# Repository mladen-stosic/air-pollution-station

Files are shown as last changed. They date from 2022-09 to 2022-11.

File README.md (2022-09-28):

# air-pollution-station
Arduino project

### Hardware used:
WeMos D1 Mini(ESP8266), PMSA003, BME280

### Project description:
Gather data from PMS and BME sensors and send them to opensensemap.org

### Implemetation:
After reset wake up PMS sensor, put it in passive mode. Try to connect to WiFi, if connection fails go to low power mode for 2 minutes.
When connected, wait 30 seconds for PMS Sensor to start sending valid values. Gather 4 different measurements from it and get their average value. This is done to increase accuracy. Gather data from BME Sensor. Send all gathered values to opensensemap.org server. Put PMS sensor to sleep. Enter deep sleep for 3 minutes, when MCU will be reset by internal clock pulling it's RST pin to GND.

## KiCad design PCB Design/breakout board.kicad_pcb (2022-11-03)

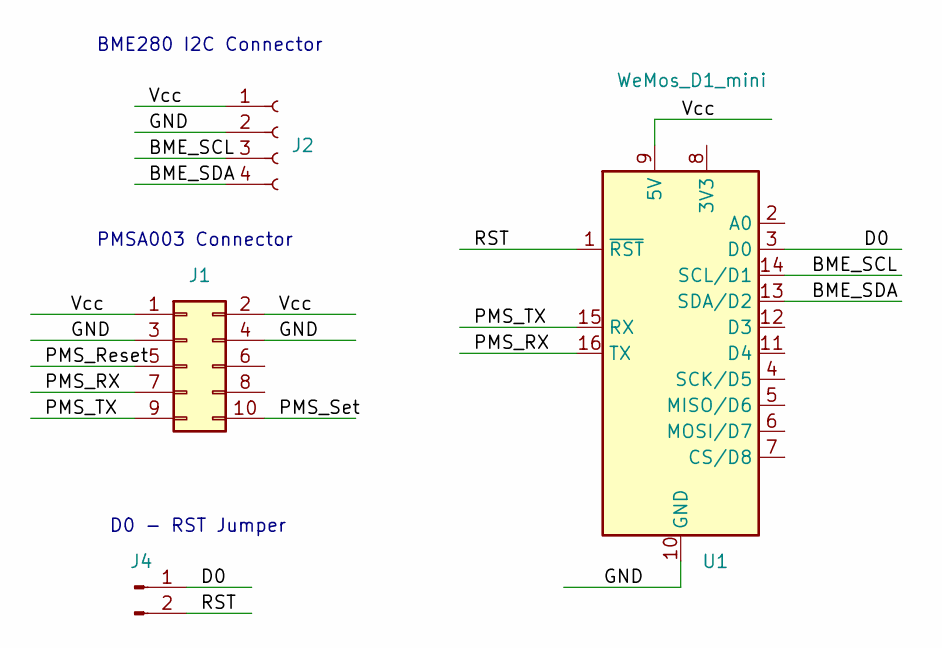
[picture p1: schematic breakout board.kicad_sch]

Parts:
J1: Conn_02x05_Odd_Even; PinHeader_2x05_P1.27mm_Vertical_SMD
J2: Conn_01x04_Female; PinHeader_1x04_P2.54mm_Vertical
J4: Conn_01x02_Male; PinHeader_1x02_P2.54mm_Vertical
U1: WeMos_D1_mini; WEMOS_D1_mini_light

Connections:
/BME_SCL: J2.3, U1.14 (SCL/D1)
/BME_SDA: J2.4, U1.13 (SDA/D2)
/D0: J4.1, U1.3 (D0)
/GND: J1.3, J1.4, J2.2, U1.10 (GND)
/PMS_RX: J1.7, U1.16 (TX)
/PMS_Reset: J1.5
/PMS_Set: J1.10
/PMS_TX: J1.9, U1.15 (RX)
/RST: J4.2, U1.1 (~RST)
/Vcc: J1.1, J1.2, J2.1, U1.9 (5V)

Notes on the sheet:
BME280 I2C Connector
PMSA003 Connector
D0 - RST Jumper

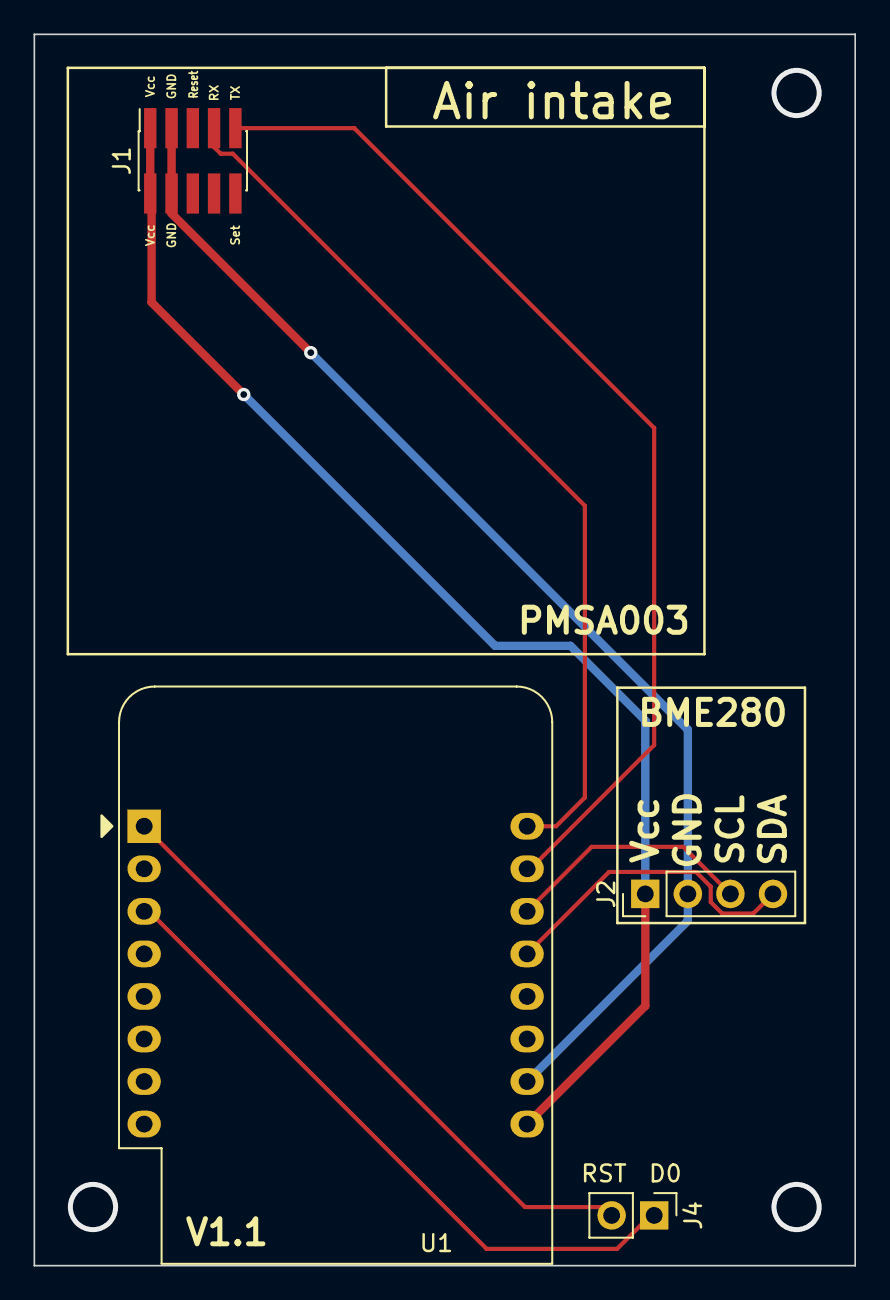
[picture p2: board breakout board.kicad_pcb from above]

Board: 2 copper layers, 49.0 x 73.5 mm, 4 parts (0 on the bottom side), 8 nets.

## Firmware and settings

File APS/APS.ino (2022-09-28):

/*

@author Mladen Stosic

@brief Air pollution station using WeMos D1 Mini,
PMSA003 and BME280
Data is sent to opensensemap.org approx every 3 minutes

Connections:

! D0 must be connected to RST !

BME280 -> WeMos D1 mini
SCL    -> SCL (PIN D1)
SDK    -> SDK (PIN D2)
GND    -> GND
VCC    -> Vcc

PMS -> WeMos D1 mini
TX  -> RX
RX  -> TX
GND -> GND
VCC -> Vcc

*/

#include <Wire.h>
#include <SPI.h>
#include <Adafruit_Sensor.h>
#include <Adafruit_BME280.h>
#include <PMS.h>
#include <ESP8266WiFi.h>
#include <stdint.h>


Adafruit_BME280 bme; // I2C
PMS pms(Serial);
PMS::DATA data;

// Network SSID
const char* ssid = "******";
const char* password = "******";

static String pressure;
static String temperature;
static String humidity;
static uint16_t pm1_0;
static uint16_t pm2_5;
static uint16_t pm10;
static uint16_t pm1_0rd[4];
static uint16_t pm2_5rd[4];
static uint16_t pm10rd[4];

static uint16_t wifiDelay = 0;

// Max Waiting time for WiFi Connection
#define WIFI_TIME_LIMIT 30*500
// Deep sleep time
#define DEEP_SLEEP_TIME 120e6
// 30s to get valid data from PMS
#define DATA_VALID_TIME 30000

// Personal sensor ID obtained from opensensemap.org
//senseBox ID
#define SENSEBOX_ID "**************"
//Sensor IDs
// Temperature - BME280
#define SENSOR1_ID "**************"
// Humidity - BME280
#define SENSOR2_ID "**************"
// Atmospheric pressure - BME280
#define SENSOR3_ID "**************"
// PM 1.0 - PMSA003
#define SENSOR4_ID "**************"
// PM 2.5 - PMSA003
#define SENSOR5_ID "**************"
// PM 10 - PMSA003
#define SENSOR6_ID "**************"

static char server[] = "ingress.opensensemap.org";
static byte mac[] = { 0xDE, 0xAD, 0xBE, 0xEF, 0xFE, 0xED };
IPAddress myIP(192, 168, 0, 42);
WiFiClient client;

// Send data to the server via WiFi
void sendData(String measurement, String sensorId){

  //Json fill
  String jsonValue = "{\"value\":";
  jsonValue += measurement;
  jsonValue += "}";

  if (client.connect(server, 80)){

    client.print("POST /boxes/"); client.print(SENSEBOX_ID); client.print("/"); client.print(sensorId); client.println(" HTTP/1.1");
    client.print("Host:");
    client.println(server);
    client.print("Authorization:");
    client.println("1cfd32ceb172e447b737c904c2eedf5d2cf9aba15ef65b8dd1015a46cafaa1e1");
    client.println("Content-Type: application/json");
    client.println("Connection: close");
    client.print("Content-Length: "); client.println(jsonValue.length());
    client.println();
    //Send data
    client.println(jsonValue);

    waitForServerResponse();

  } 
}

void waitForServerResponse () {
  if (!client.connected()) {
      client.stop();
      // Disable power to sensors
      pms.sleep();
      // Deep sleep for 1 minute
      ESP.deepSleep(DEEP_SLEEP_TIME / 2);
  }
}

// Read values from PMS Air quality sensor
void readPMS() {
  static uint8_t i;
  static uint8_t data_read;
  i = 0;
  data_read = 0;
  while (!data_read){
    pms.requestRead();
    if (pms.readUntil(data)){
      pm1_0rd[i] = data.PM_AE_UG_1_0;
      pm2_5rd[i] = data.PM_AE_UG_2_5;
      pm10rd[i]  = data.PM_AE_UG_10_0;
      i++;
      if (i > 3){
        data_read = 1;
      }
    }
  }
  // Calculate average value 
  pm1_0 = 0;
  pm2_5 = 0;
  pm10  = 0;
  for (i = 0; i < 4; i++){
    pm1_0 += pm1_0rd[i] >> 2;
    pm2_5 += pm2_5rd[i] >> 2;
    pm10  += pm10rd[i] >> 2;
  }
}

// Read values from BME280 sensor
void readBME() {
    temperature = String(bme.readTemperature(), 1);
    pressure = String(bme.readPressure() / 100.0F, 1);
    humidity = String(bme.readHumidity(),0);
}

void setup() {
    // Init hardware
    bme.begin(0x76);
    Serial.begin(9600);

    // Enable power to sensors
    pms.passiveMode();
    pms.wakeUp();

    // Connect to WiFi
    WiFi.hostname("Name");
    WiFi.begin(ssid, password);
    wifiDelay = 0;

    // Wait for wifi connection
    while ((WiFi.status() != WL_CONNECTED) && (wifiDelay < WIFI_TIME_LIMIT)){
        wifiDelay += 500; // Store wifi connection elapsed time 
        delay(500);
        Serial.print(".");
    }
    // If unable to connect to WiFi reset MCU
    if (wifiDelay > WIFI_TIME_LIMIT){
      // Disable power to sensors
      pms.sleep();
      // Deep sleep for 1 minute
      ESP.deepSleep(DEEP_SLEEP_TIME / 2);
    }

    // Wait for 30s to get valid data from PMS Sensor
    delay(DATA_VALID_TIME);
    // TODO Light sleep??

    // Read sensor data
    readBME();
    readPMS();

    // Send values to server via WiFi
    sendData(String(pm1_0), SENSOR4_ID);
    sendData(String(pm2_5), SENSOR5_ID);
    sendData(String(pm10), SENSOR6_ID);
    sendData(temperature, SENSOR1_ID);
    sendData(humidity, SENSOR2_ID);
    sendData(pressure, SENSOR3_ID);
    

    // Disable power to sensors
    pms.sleep();
    // Deep sleep for 2 minutes
    ESP.deepSleep(DEEP_SLEEP_TIME);
}

void loop() {
}
